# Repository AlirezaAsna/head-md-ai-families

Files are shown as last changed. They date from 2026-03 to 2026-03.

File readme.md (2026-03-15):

# We were there, differently

Physical interaction prototype using ESP8266 / ESP32, electromagnets, LEDs, and behavior-based logic to simulate an AI-driven relational object.

This project was developed for Master Media Design – HEAD Genève in the course AI in Family.  
The goal is to create a pair of objects that represent a relationship between two people through physical interaction, fading behavior over time, and AI-like interpretation of usage patterns.

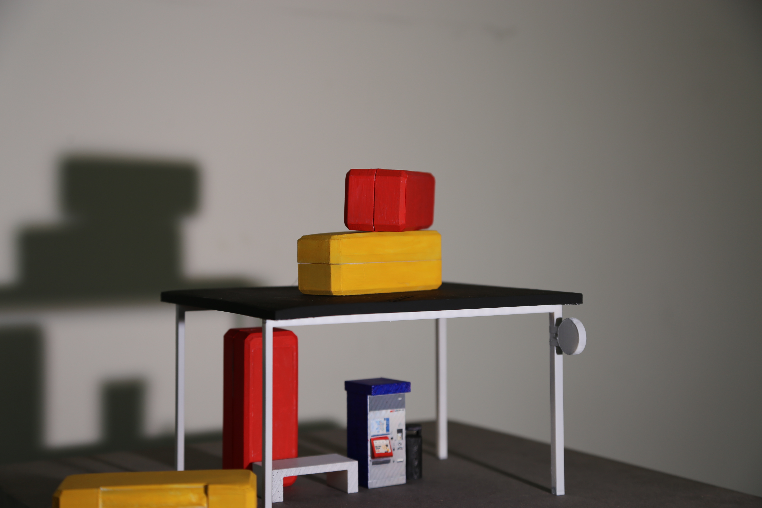
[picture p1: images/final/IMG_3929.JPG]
main image


## Concept

Two people share a pair of small magnetic objects before separation.

While together, they can casually play with the objects during conversation.  
The interaction is simple, tactile, and does not require instructions.

After separation, each person keeps one object.

Over time, the object slowly changes its behavior depending on how often it is used.  
Magnets weaken, lights fade, and the object may try to attract attention.

The system does not react instantly.  
Instead, it tracks interaction patterns and changes state over time to simulate interpretation.

The objects can only fully return to their original state when they meet again.

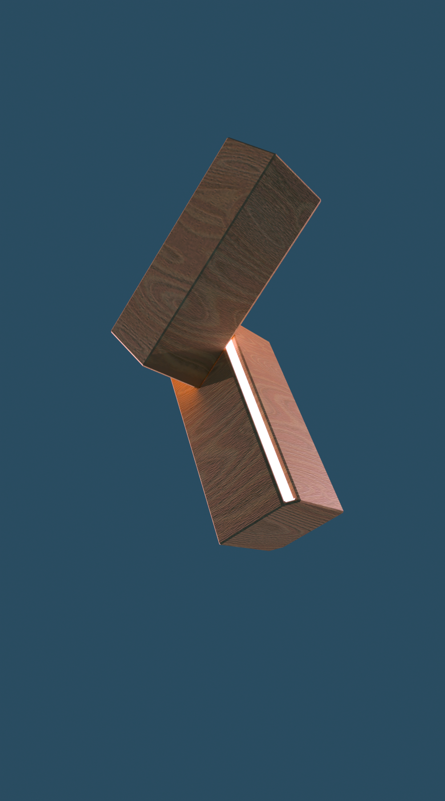
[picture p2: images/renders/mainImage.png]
concept image


## Features

- ESP8266 / ESP32 microcontroller control
- Electromagnet strength control (PWM)
- WS2812 LED feedback
- Behavior stages
- Local Wi-Fi control page
- Interaction tracking logic
- AI-style reminder behavior
- 5V adaptor powered
- Compact enclosure with embedded magnets

## Hardware

- ESP8266 (Wemos D1 mini) / ESP32 (prototype)
- Electromagnet 5V
- Neodymium magnets
- TIP122 / MOSFET driver
- Flyback diode
- 5V power adaptor
- WS2812 LED ring / strip
- IMU sensor (optional / planned)
- NFC module (planned)
- 3D printed internal structure

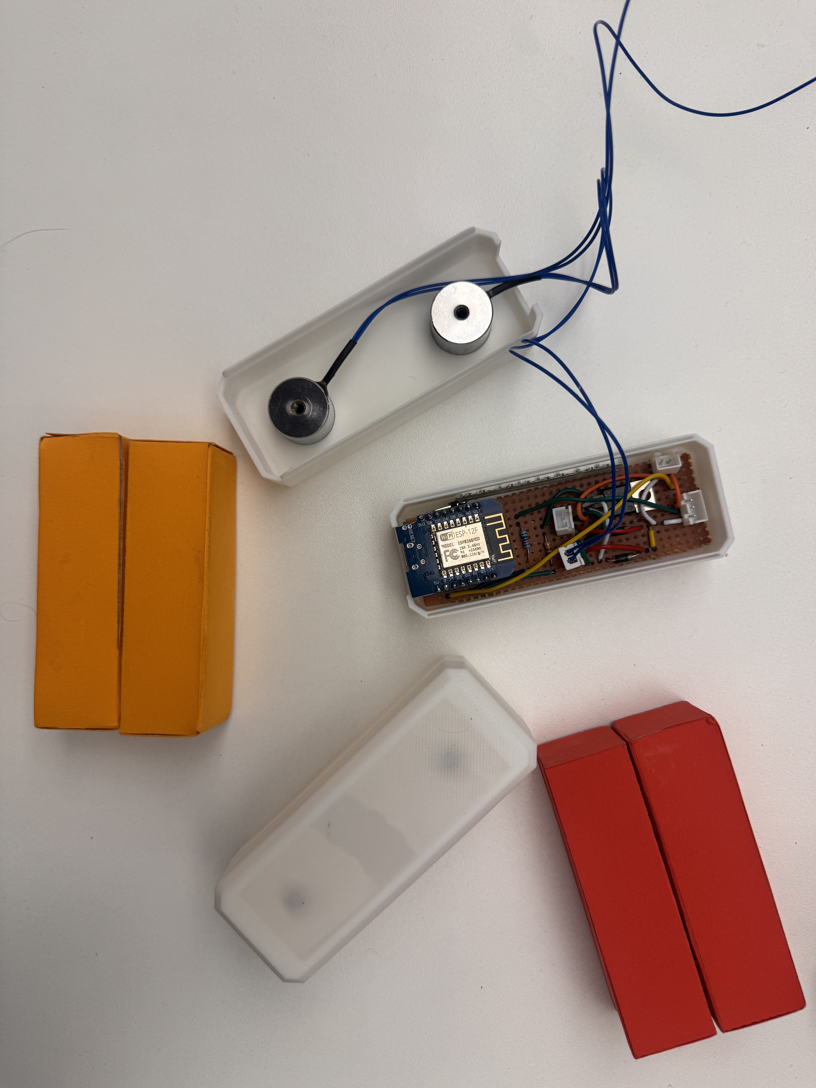
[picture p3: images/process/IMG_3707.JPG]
hardware


Power layout:

```
5V adaptor → Magnet + LED
ESP powered from 5V
Common GND shared
```

## Circuit logic

Magnet control

```
5V → Magnet → TIP122 → GND
GPIO → resistor → TIP122 base
Flyback diode across magnet
```

LED control

```
GPIO → DI
5V → VCC
GND shared
```

All grounds must be connected.

## Behavior System

The object runs in multiple states.

Stage 1 — Active  
Full magnet strength  
Stable breathing light  

Stage 2 — Unstable  
Reduced magnet strength  
Directional light  

Stage 3 — Lost  
Magnet off  
Blinking light  

Rest / Standby  
Magnets off  
Slow breathing light  

States change based on interaction patterns, not instant input.

## AI Logic (Behavior Based)

No real machine learning is used.

AI is simulated through pattern tracking:

- frequency of interaction
- duration of inactivity
- time between interactions
- duration of use
- repetition habits

Based on this, the system changes state over time.

```
active → strong response
less use → weaker response
no use → standby
long inactivity → reminder
reunion → reset
```

The goal is to create the feeling that the object interprets the relationship.

## Process

The first prototype was developed using ESP32.  
All tests were done on breadboard using ESP32, LEDs, and electromagnets to validate the behavior system and stage logic.

However, the final object needed to be very small, and ESP32 boards were too large for the enclosure.  
Because of the size limitation, the system was rebuilt using ESP8266 (Wemos D1 mini), which is smaller but still supports Wi-Fi, PWM, and LED control.

For the current prototype, the system is powered with a 5V adaptor instead of battery, in order to simplify the electronics and keep the object compact.  
Battery integration is planned for later versions.

<table>
<tr>
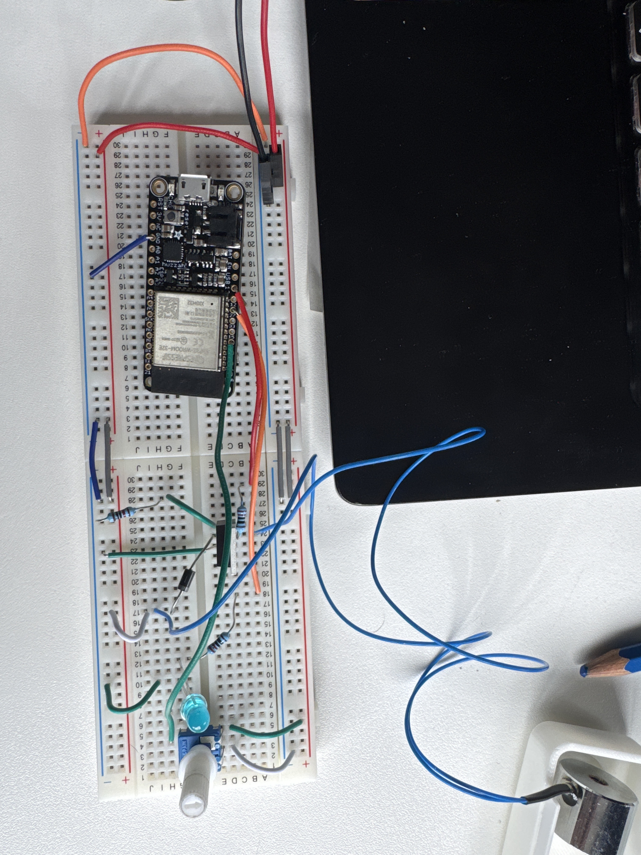
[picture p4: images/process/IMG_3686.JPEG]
<td></td>
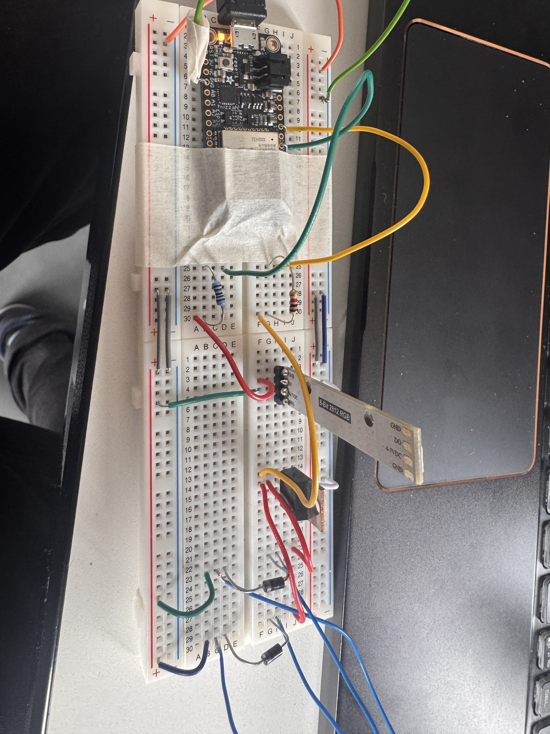
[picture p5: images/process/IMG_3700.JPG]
<td></td>
</tr>
<tr>
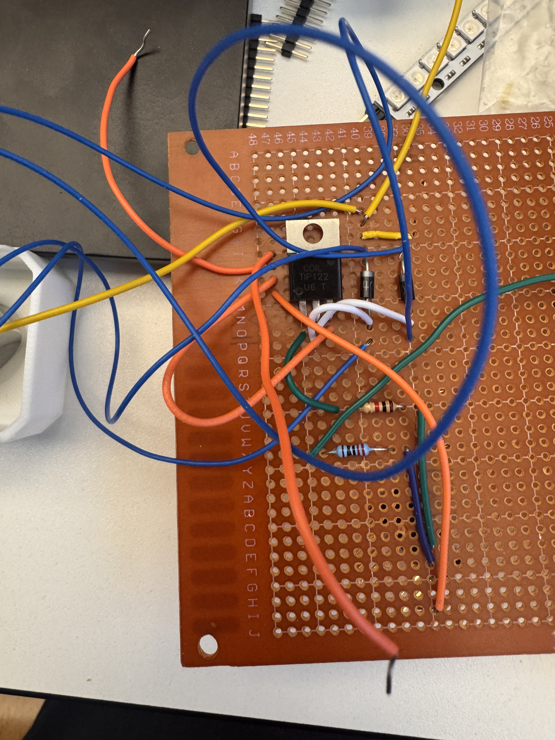
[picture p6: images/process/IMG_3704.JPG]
<td></td>
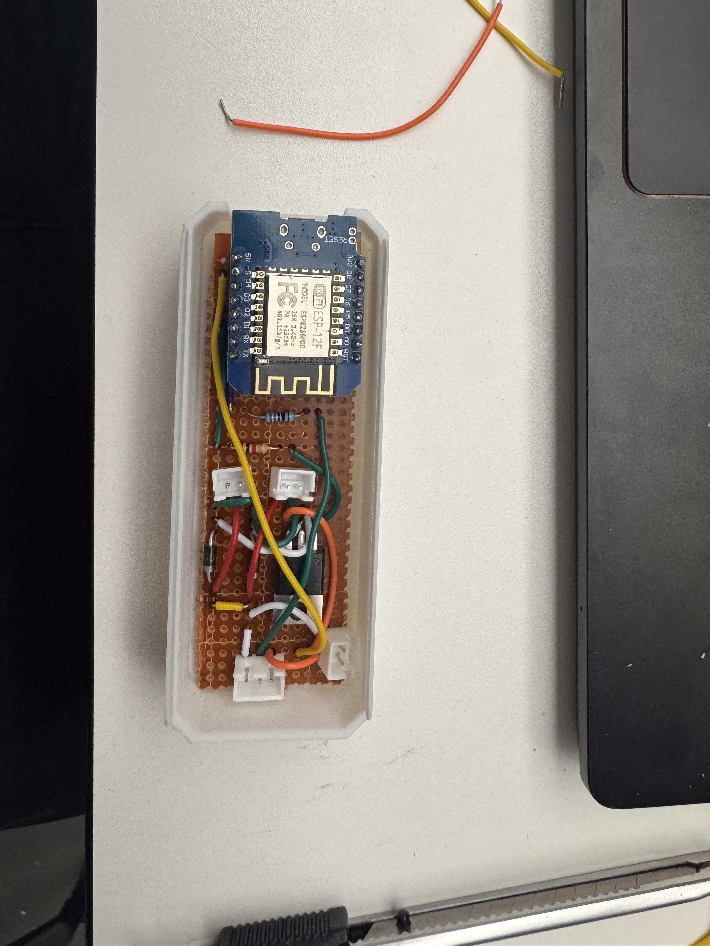
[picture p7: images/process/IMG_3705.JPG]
<td></td>
</tr>
<tr>
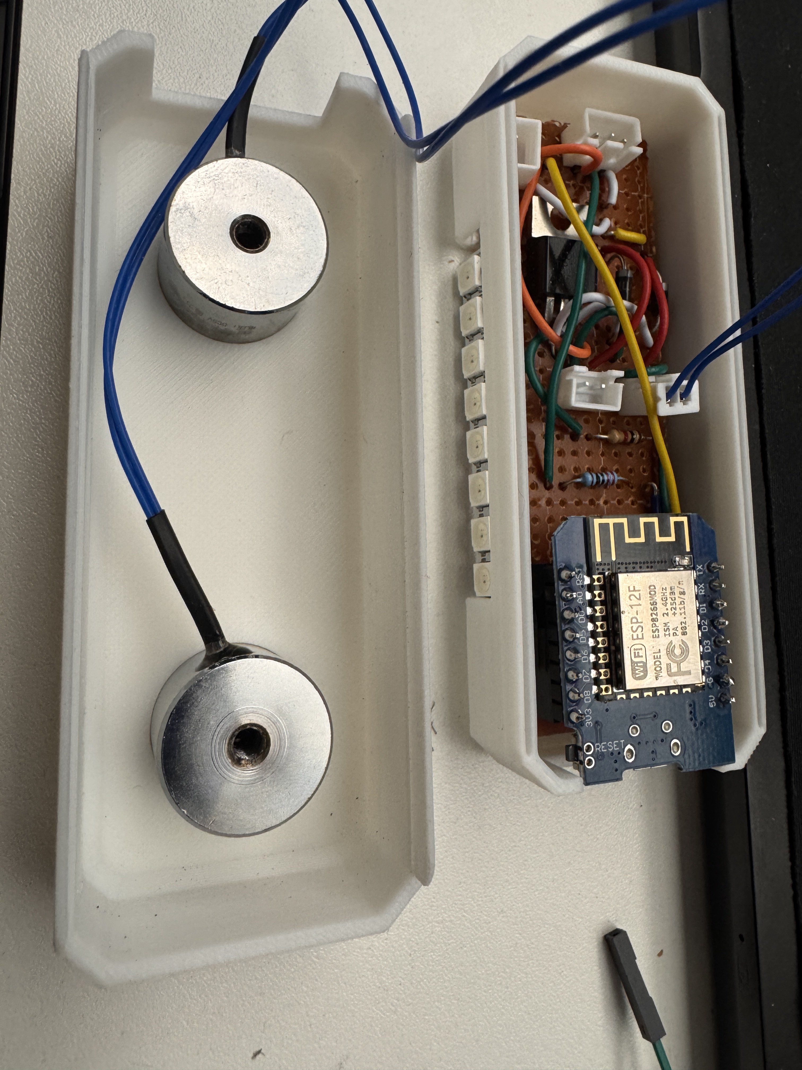
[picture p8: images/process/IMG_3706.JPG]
<td></td>
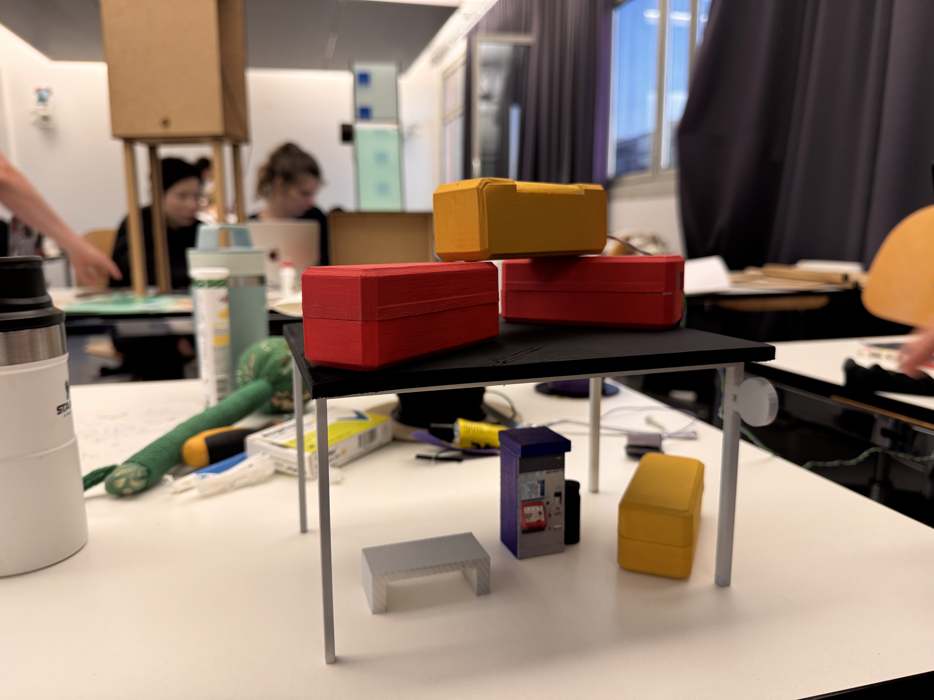
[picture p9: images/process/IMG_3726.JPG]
<td></td>
</tr>
</table>

## Installation

For exhibition, the object needs to provide a short and understandable experience.

Because of this, the behavior system must be adjusted to react faster than in real use.

In the installation version, the interaction can be influenced by distance between the two objects.  
Using NFC or similar proximity detection, the system can change stages depending on how close the objects are.

Possible installation behavior:

- close distance → strong magnets / stable light
- medium distance → unstable feedback
- far distance → fading / standby
- reunion → full activation

During interaction, stronger light or vibration feedback can show that the system is detecting patterns.

## Future Perspective

Future versions of the project may include more complex behavior analysis and additional hardware.

Possible next steps:

- add NFC to detect distance between objects
- add vibration feedback
- add battery power system
- use Raspberry Pi or similar board for behavior analysis
- allow external processing for pattern recognition
- improve reminder logic
- connect multiple objects in one system
- smaller and more robust enclosure
- more precise magnet control

## Designers

Alireza Asnavandi  
[Zainab Ouriachi](https://github.com/mynameiszainabouriachi-stack)

Master Media Design  
HEAD Genève  
2026

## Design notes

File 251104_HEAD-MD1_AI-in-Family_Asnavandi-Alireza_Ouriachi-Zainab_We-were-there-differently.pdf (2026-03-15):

Alireza Asnavandi | Zainab Ouriachi
We were there, differently
Master Media Design 1 | 23-02-2026
AI in Family

We were there,

# Differently

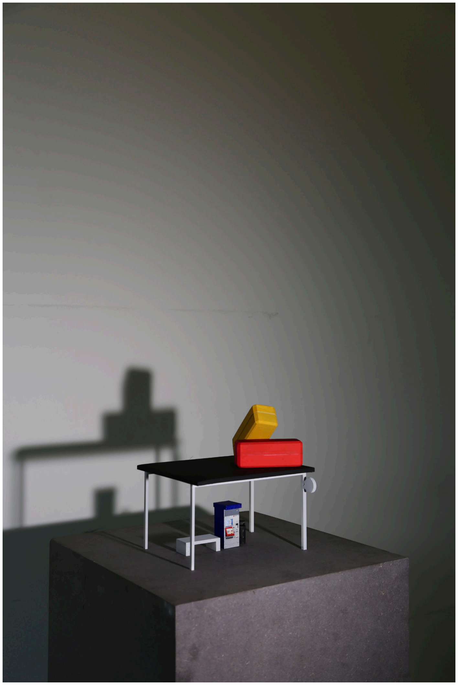
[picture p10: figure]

This project presents a pair of small magnetic objects shared between two people during their final moments together before separation. The interaction is intentionally simple: while talking, they casually connect and move the objects in their hands, letting the magnets guide natural and satisfying movements.

The objects act as a quiet third presence. They do not record speech or capture specific content. Instead, they observe how the objects are used, how often they are touched, how long they are held, and how interaction changes over time. The system treats these patterns of interaction as a form of memory.

After goodbye, each person keeps one object. Over time, its behavior slowly changes, reflecting how shared moments transform once distance begins. The response of the object fades, becomes unstable, or tries to attract attention, depending on how it is used. The system does not react instantly, but interprets interaction over time, creating the impression that the object understands the relationship.

The object can be reactivated through use, but it cannot fully return to its original state alone. To restore it completely, the two objects must meet again and be played with together. In the installation version, the distance between the objects can also influence their behavior, allowing separation and reunion to become visible through changes in light, magnet strength, and feedback. In this way, the objects do not store memories, but continuously recreate them through interaction.

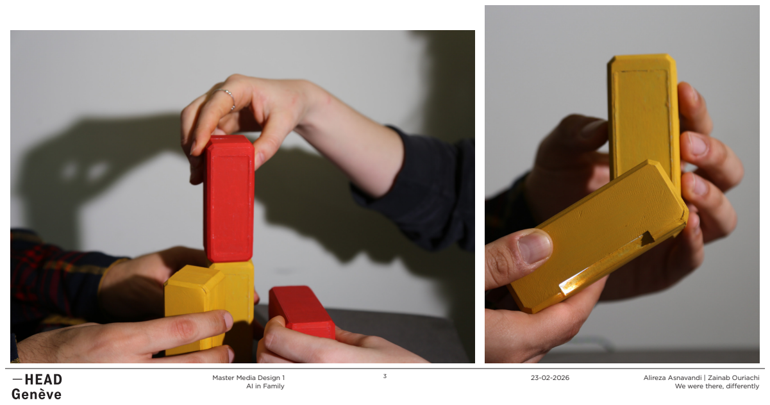
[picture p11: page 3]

# User Journey

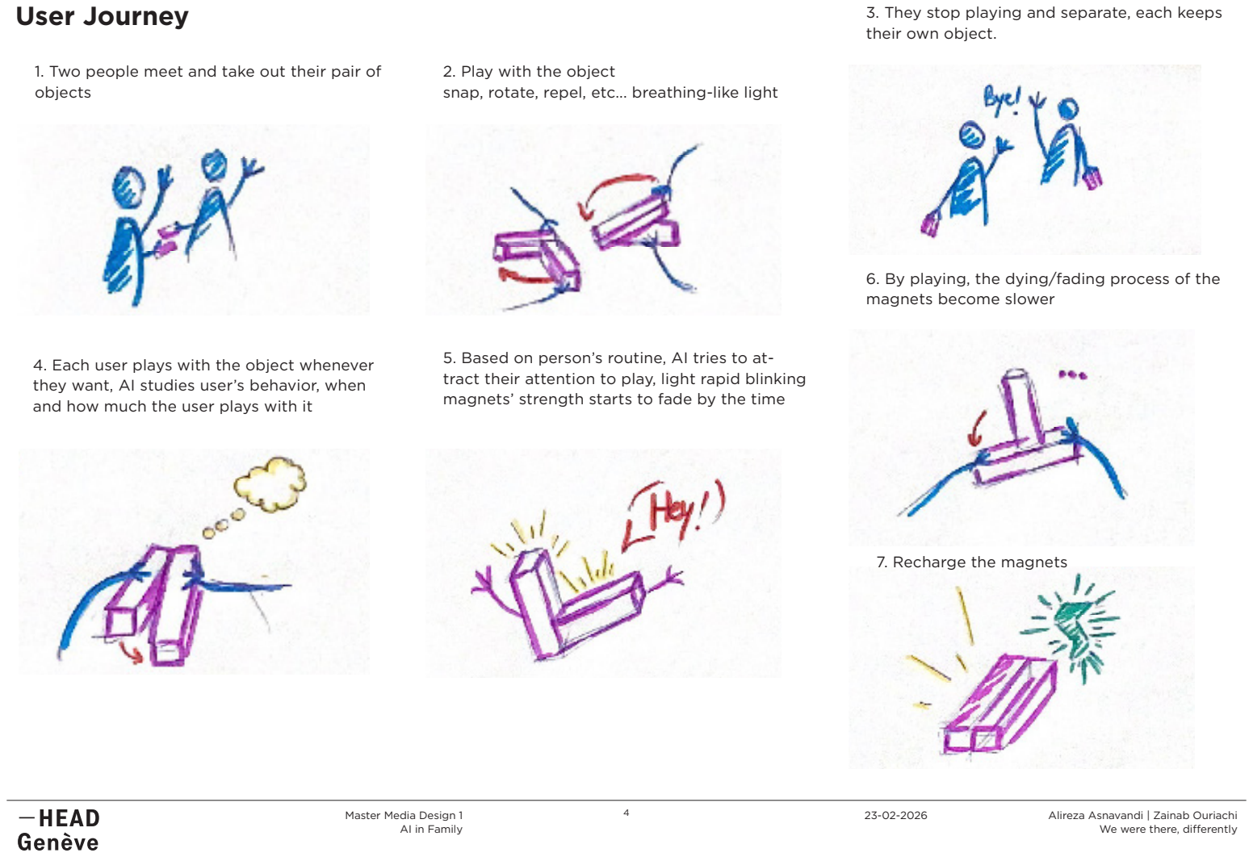
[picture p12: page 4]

2. Play with the object
snap, rotate, repel, etc... breathing-like light
3. They stop playing and separate, each keeps their own object.
4. Each user plays with the object whenever they want, AI studies user’s behavior, when and how much the user plays with it
5. Based on person’s routine, AI tries to attract their attention to play, light rapid blinking magnets’ strength starts to fade by the time
6. By playing, the dying/fading process of the magnets become slower
1. Two people meet and take out their pair of objects
7. Recharge the magnets

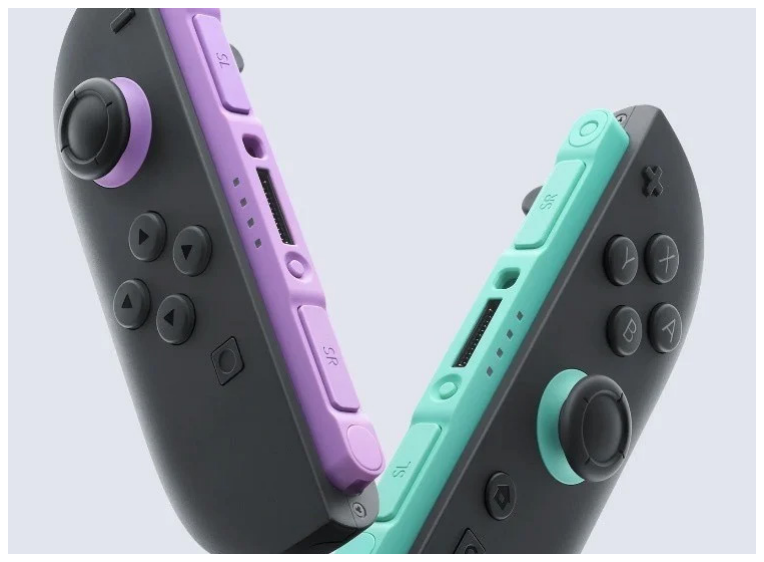
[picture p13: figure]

# Context research

This project begins with the idea of distance and memory. When people are physically apart, especially when living abroad, relationships are often sustained through what we remember rather than what we share in the present. Human memory is not exact or stable; even shared moments are remembered differently by each person. We also considered the idea of chosen family, where strong emotional bonds define belonging beyond blood or legal ties. From this perspective, we explore how distance slowly reshapes what once felt like a shared experience.

AI as a subtle social mediator: here, artificial intelligence doesn’t just provide information, it directs and shapes a shared human experience (a dinner) without dominating.

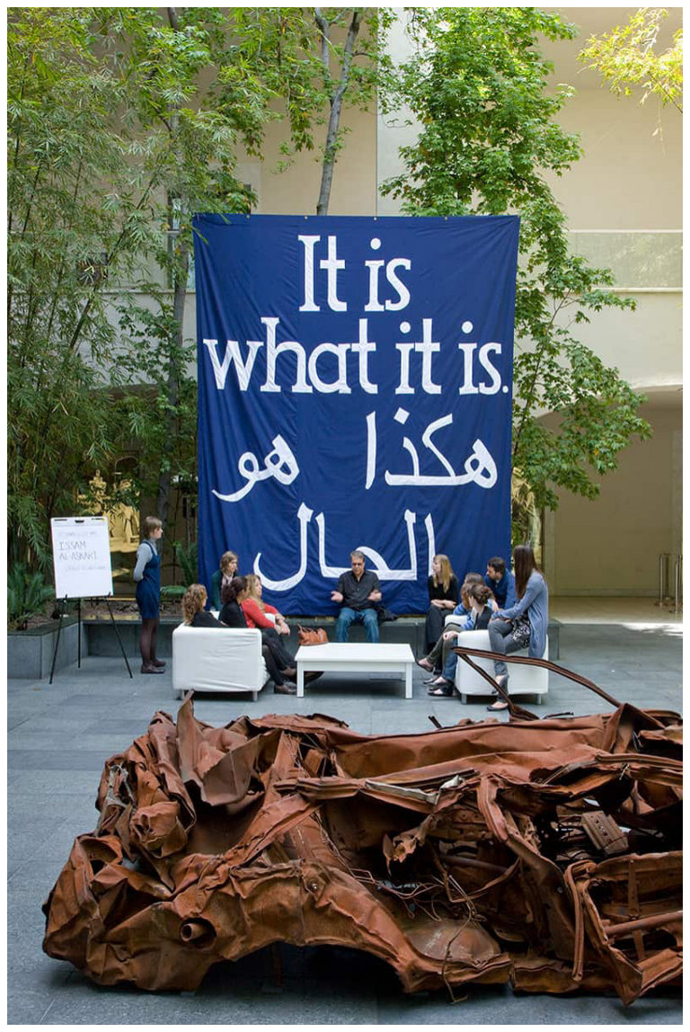
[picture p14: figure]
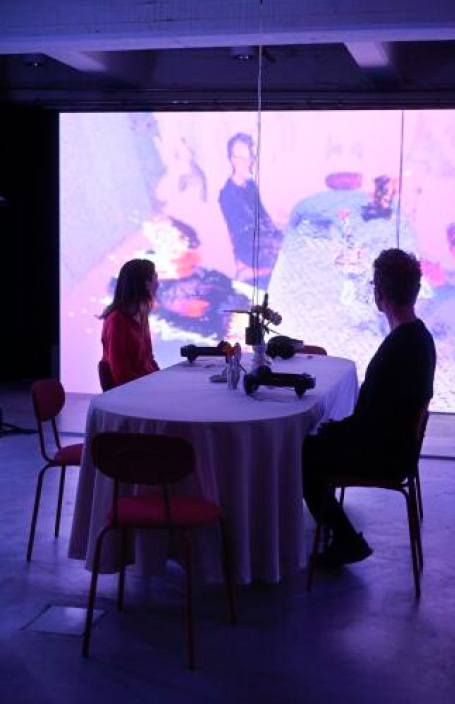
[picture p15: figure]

Be My Guest!
A Dinner Event
Hosted by Artificial
Intelligence
MIT MEDIA LAB

It Is What It Is
Jeremy Deller

To grow, we must
forget… but now
AI remembers
everything

An exploration of how situations themselves can function as artworks. It focuses on context, participation, and relational dynamics rather than on a fixed object as the main artistic outcome.

This text discusses how forgetting is part of how memory works, not a flaw. It challenges the idea of perfect recall and highlights the role of absence, loss, and transformation in memory

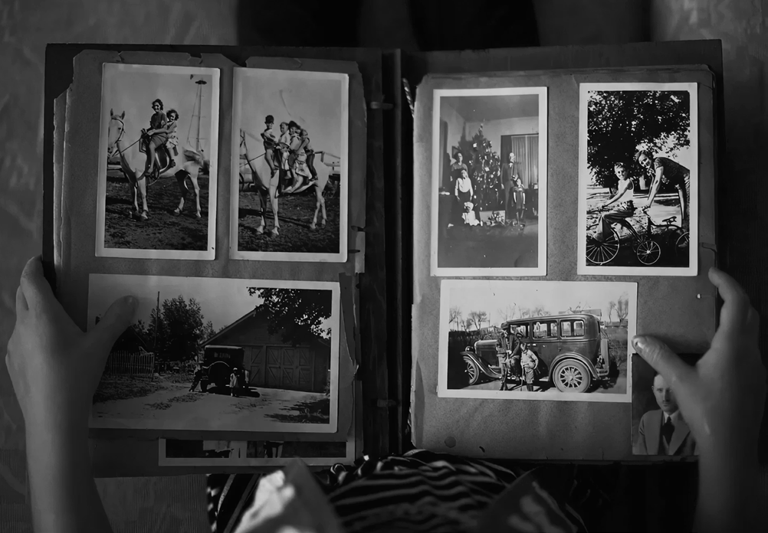
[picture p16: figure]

# The Interface - Key visuals

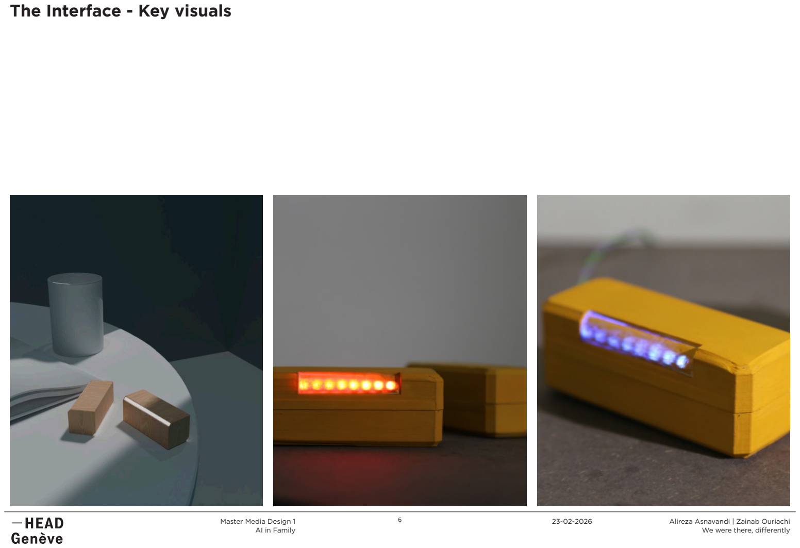
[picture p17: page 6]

# User Tests

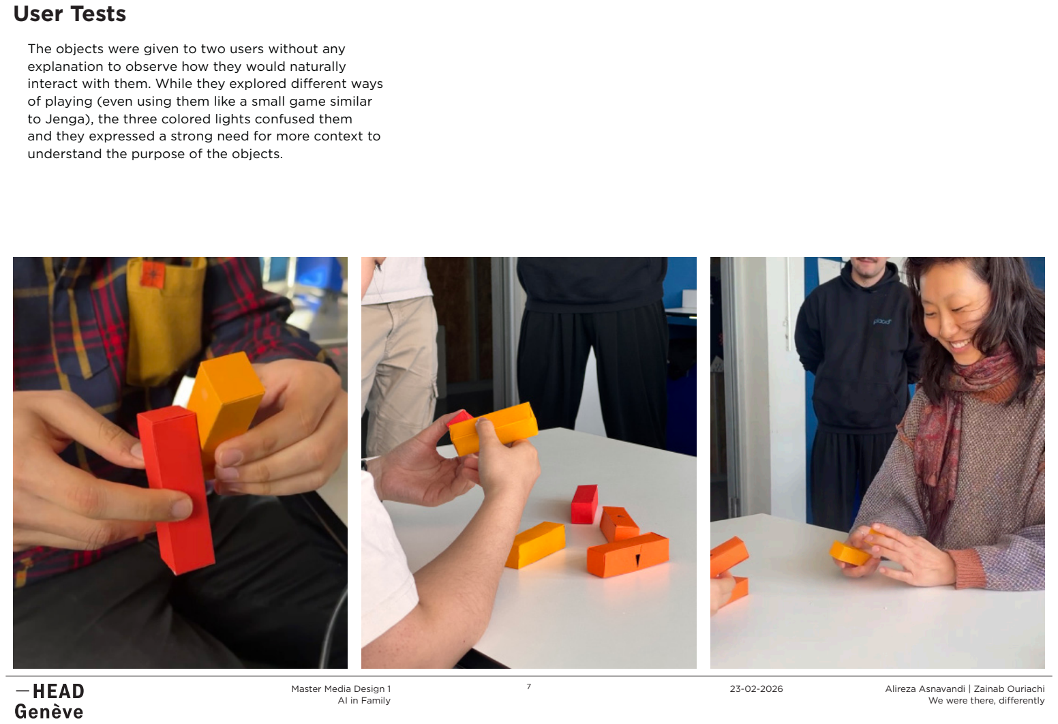
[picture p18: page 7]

The objects were given to two users without any explanation to observe how they would naturally interact with them. While they explored different ways of playing (even using them like a small game similar to Jenga), the three colored lights confused them and they expressed a strong need for more context to understand the purpose of the objects.

# Technical diagram

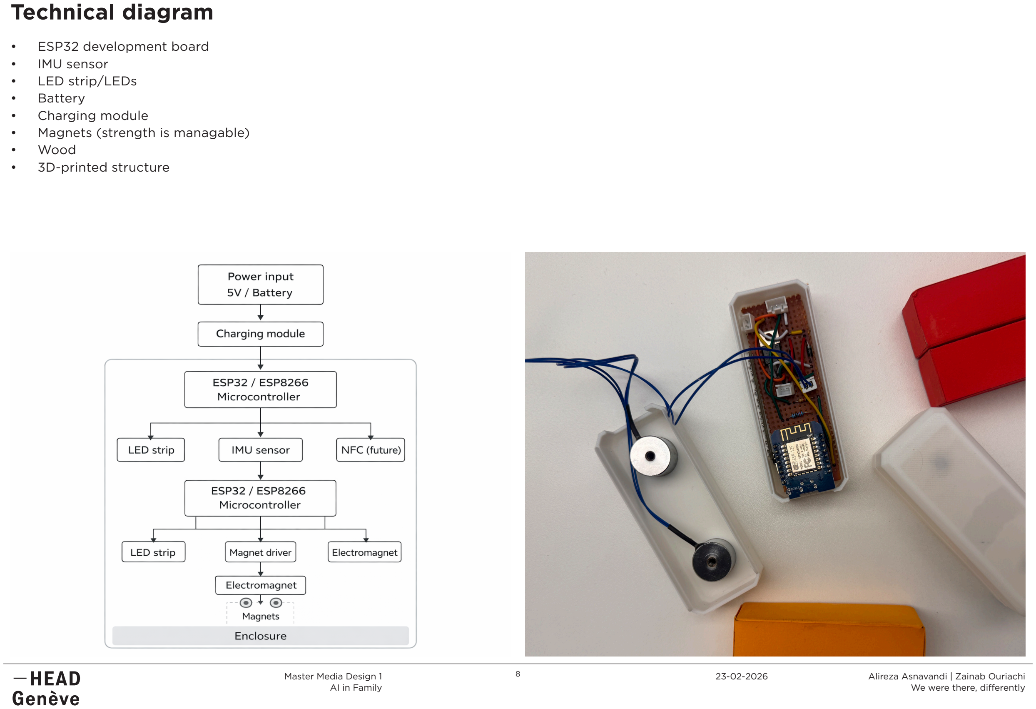
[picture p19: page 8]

• ESP32 development board • IMU sensor
• LED strip/LEDs
• Battery
• Charging module
• Magnets (strength is managable) • Wood
• 3D-printed structure

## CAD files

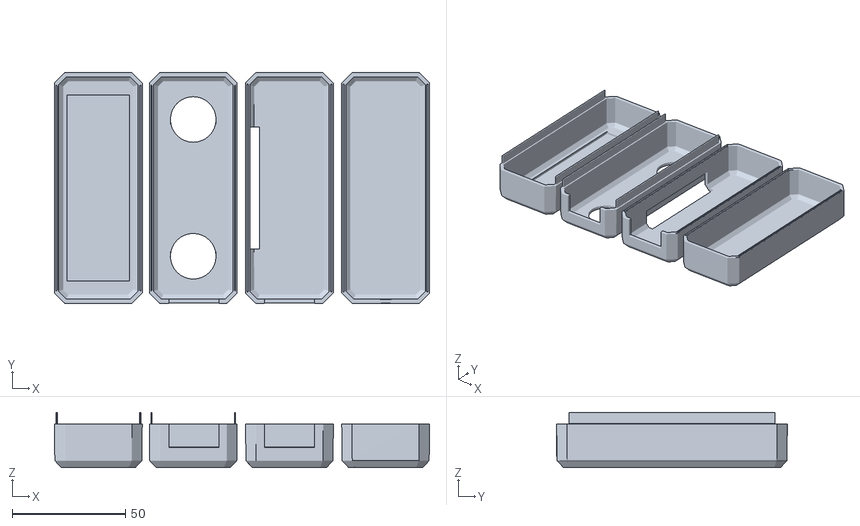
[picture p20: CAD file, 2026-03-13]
3d-models/3d-print-files/StructureTwo.stl
165.3 x 101.7 x 24.3

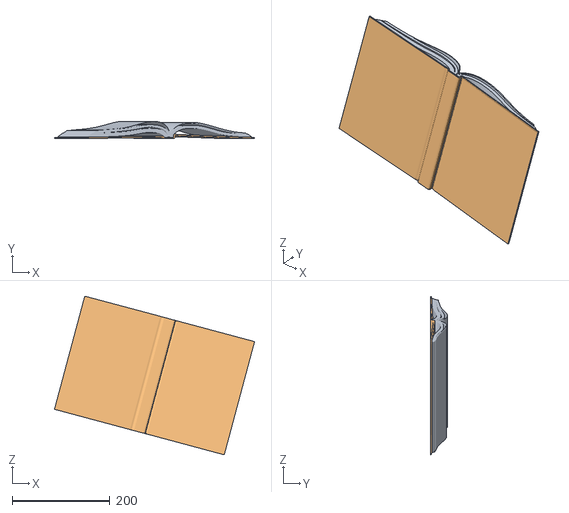
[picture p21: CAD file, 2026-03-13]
3d-models/book.obj
409.9 x 35.6 x 324.9
Obj3d66_10155080_6_8
Obj3d66_10155080_7_191

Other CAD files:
3d-models/Shape.blend
3d-models/StructureOne.blend
3d-models/StructureTwo.blend
3d-models/assets/materials/pine-wood_ba3a205a-6e76-46a9-96b0-ee3a93ee0699/pine-wood_2K_f99ce092-faaa-41e1-8bfa-006d5499ce04.blend
3d-models/keyAnimation.blend
3d-models/lightAnimation.blend
3d-models/lightsOff.blend
3d-models/mainImage.blend

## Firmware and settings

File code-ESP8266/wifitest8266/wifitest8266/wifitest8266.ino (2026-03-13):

#include <ESP8266WiFi.h>
#include <ESP8266WebServer.h>
#include <Adafruit_NeoPixel.h>
#include <math.h>

const char* ssid = "Media_Design_Network";
const char* password = "mdnetwork";

const int magnetPin = D1;
const int ledPin = D2;
#define NUMPIXELS 8

ESP8266WebServer server(80);
Adafruit_NeoPixel strip(NUMPIXELS, ledPin, NEO_GRB + NEO_KHZ800);

enum Mode {
  MODE_STAGE1,
  MODE_STAGE2,
  MODE_STAGE3,
  MODE_REST
};

Mode currentMode = MODE_REST;

// ---------- WEB PAGE ----------
const char webpage[] PROGMEM = R"rawliteral(
<!DOCTYPE html>
<html>
<head>
  <meta name="viewport" content="width=device-width, initial-scale=1">
  <title>Magnet Control</title>
  <style>
    body { font-family: Arial; text-align: center; background: #111; color: #eee; margin-top: 40px; }
    button {
      width: 220px; height: 56px; margin: 10px; font-size: 18px;
      border: none; border-radius: 12px; cursor: pointer;
    }
    .b1 { background: #ffffff; color: #111; }
    .b2 { background: orange; color: #111; }
    .b3 { background: #ff3b30; color: white; }
    .b4 { background: #4da3ff; color: white; }
  </style>
</head>
<body>
  <h1>Wemos Control</h1>
  <p>Select a stage:</p>
  <p><a href="/stage1"><button class="b1">Playing together</button></a></p>
  <p><a href="/stage2"><button class="b2">It's been a while you haven't meet</button></a></p>
  <p><a href="/stage3"><button class="b3">You need to meet him!</button></a></p>
  <p><a href="/rest"><button class="b4">Take a moment to think about him</button></a></p>
</body>
</html>
)rawliteral";

// ---------- HELPERS ----------
void setAllPixels(uint8_t r, uint8_t g, uint8_t b) {
  for (int i = 0; i < NUMPIXELS; i++) {
    strip.setPixelColor(i, strip.Color(r, g, b));
  }
  strip.show();
}

void clearStrip() {
  strip.clear();
  strip.show();
}

void handleRoot() {
  server.send_P(200, "text/html", webpage);
}

void handleStage1() {
  currentMode = MODE_STAGE1;
  server.sendHeader("Location", "/");
  server.send(303);
}

void handleStage2() {
  currentMode = MODE_STAGE2;
  server.sendHeader("Location", "/");
  server.send(303);
}

void handleStage3() {
  currentMode = MODE_STAGE3;
  server.sendHeader("Location", "/");
  server.send(303);
}

void handleRest() {
  currentMode = MODE_REST;
  server.sendHeader("Location", "/");
  server.send(303);
}

// ---------- ANIMATION STATE ----------
unsigned long lastAnim = 0;
int waveIndex = 0;
int inwardStep = 0;
bool blinkState = false;

// ---------- STAGE LOGIC ----------
void runStage1() {
  // Full power magnets
  analogWrite(magnetPin, 1023);

  // White wave
  if (millis() - lastAnim > 120) {
    lastAnim = millis();
    strip.clear();
    strip.setPixelColor(waveIndex, strip.Color(255, 255, 255));
    strip.show();
    waveIndex++;
    if (waveIndex >= NUMPIXELS) waveIndex = 0;
  }
}

void runStage2() {
  // Half power magnets
  analogWrite(magnetPin, 512);

  // From ends to center, orange
  if (millis() - lastAnim > 250) {
    lastAnim = millis();
    strip.clear();

    if (inwardStep >= 0) {
      strip.setPixelColor(0, strip.Color(255, 80, 0));
      strip.setPixelColor(7, strip.Color(255, 80, 0));
    }
    if (inwardStep >= 1) {
      strip.setPixelColor(1, strip.Color(255, 80, 0));
      strip.setPixelColor(6, strip.Color(255, 80, 0));
    }
    if (inwardStep >= 2) {
      strip.setPixelColor(2, strip.Color(255, 80, 0));
      strip.setPixelColor(5, strip.Color(255, 80, 0));
    }
    if (inwardStep >= 3) {
      strip.setPixelColor(3, strip.Color(255, 80, 0));
      strip.setPixelColor(4, strip.Color(255, 80, 0));
    }

    strip.show();
    inwardStep++;
    if (inwardStep > 4) inwardStep = 0;
  }
}

void runStage3() {
  // Zero power magnets
  analogWrite(magnetPin, 0);

  // Blinking red
  if (millis() - lastAnim > 300) {
    lastAnim = millis();
    blinkState = !blinkState;

    if (blinkState) {
      setAllPixels(255, 0, 0);
    } else {
      clearStrip();
    }
  }
}

void runRest() {
  // Magnets off
  analogWrite(magnetPin, 0);

  // Smooth breathing standby light
  float t = millis() / 1000.0;
  float breath = (sin(t * 2.0) + 1.0) * 0.5;   // 0..1
  uint8_t brightness = (uint8_t)(breath * 80.0); // soft standby glow

  for (int i = 0; i < NUMPIXELS; i++) {
    strip.setPixelColor(i, strip.Color(0, 0, brightness));
  }
  strip.show();
}

void setup() {
  pinMode(magnetPin, OUTPUT);
  analogWriteRange(1023);

  strip.begin();
  strip.show();

  Serial.begin(115200);
  delay(500);

  WiFi.mode(WIFI_STA);
  WiFi.begin(ssid, password);

  Serial.print("Connecting");
  while (WiFi.status() != WL_CONNECTED) {
    delay(300);
    Serial.print(".");
  }

  Serial.println();
  Serial.print("Connected! IP: ");
  Serial.println(WiFi.localIP());

  server.on("/", handleRoot);
  server.on("/stage1", handleStage1);
  server.on("/stage2", handleStage2);
  server.on("/stage3", handleStage3);
  server.on("/rest", handleRest);
  server.begin();

  Serial.println("Web server started");
}

void loop() {
  server.handleClient();

  switch (currentMode) {
    case MODE_STAGE1:
      runStage1();
      break;
    case MODE_STAGE2:
      runStage2();
      break;
    case MODE_STAGE3:
      runStage3();
      break;
    case MODE_REST:
      runRest();
      break;
  }
}

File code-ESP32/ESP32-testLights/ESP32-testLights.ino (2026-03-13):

const int magnetPin = 13;
const int ledPin = 27;

void setup() {
  ledcAttach(magnetPin, 5000, 8);
  ledcAttach(ledPin, 5000, 8);
}

void loop() {
  for (int pwm = 255; pwm >= 0; pwm--) {
    ledcWrite(magnetPin, pwm);
    ledcWrite(ledPin, pwm);
    delay(30);
  }

  delay(1000);

  for (int pwm = 0; pwm <= 255; pwm ++) {
    ledcWrite(magnetPin, pwm);
    ledcWrite(ledPin, pwm);
    delay(30);
  }

  delay(1000);
}

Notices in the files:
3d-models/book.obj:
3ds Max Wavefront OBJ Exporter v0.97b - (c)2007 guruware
